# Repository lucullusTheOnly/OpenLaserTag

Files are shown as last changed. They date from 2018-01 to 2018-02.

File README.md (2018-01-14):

# OpenLaserTag
OperLaserTag is a DIY system for the popular game lasertag. I have designed it for high flexibility for game modes. With this article series and a little knowledge about electronics with microcontrollers like the Arduino you should be able to build your own lasertag system.
The work on this project isn't finished jet and I would be glad to receive some honest hints about what the system should be able to do and how this can be accomplished.

The System consists of the Arduino-based tagger, which is connected to a smartphone via bluetooth. The tagger uses an infrared LED and a lens to send a beam of modulated IR-light in the direction the tagger is pointed to. This works similar to normal IR-remotes, for example for your TV. The tagger is connected to a number of receiver modules, which are located on a vest, so that you can be hit by other players with their tagger. The Arduino informs the smartphone whenever something happens via a bluetooth-serial module and the smartphone does all the management of the game.

At the current state the tagger systems of different players don't have any contact. I designed the system, so that the game follows rules written in a XML-file and will end in a given time limit. This gives great flexibility, because you don't have to set up a communication system over the whole game field (which may be quite big). But this feature (over a limited range) could be added using 433MHz transmission modules.

For more information please visit the Wiki.

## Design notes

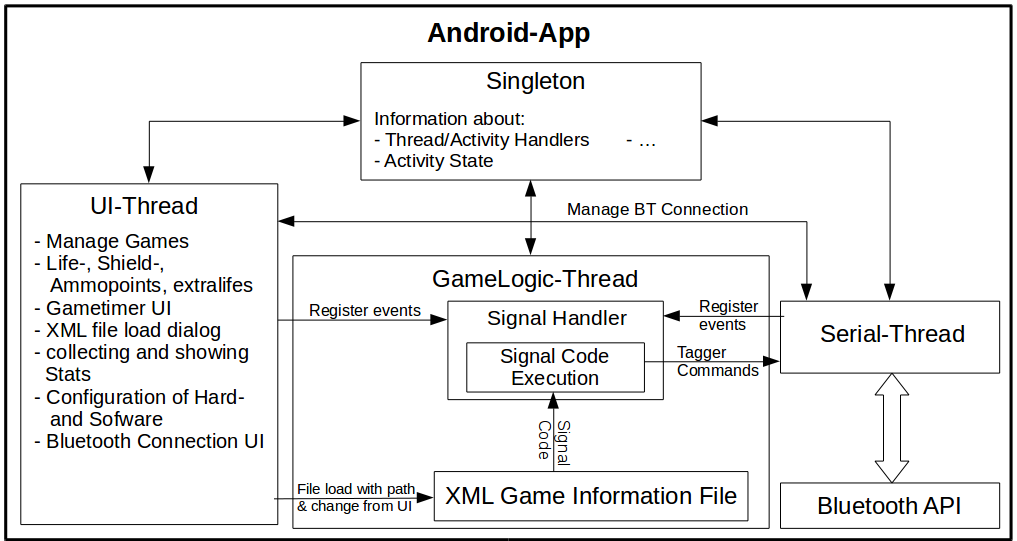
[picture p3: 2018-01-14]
Wiki/LaserTag_schematic_app.png

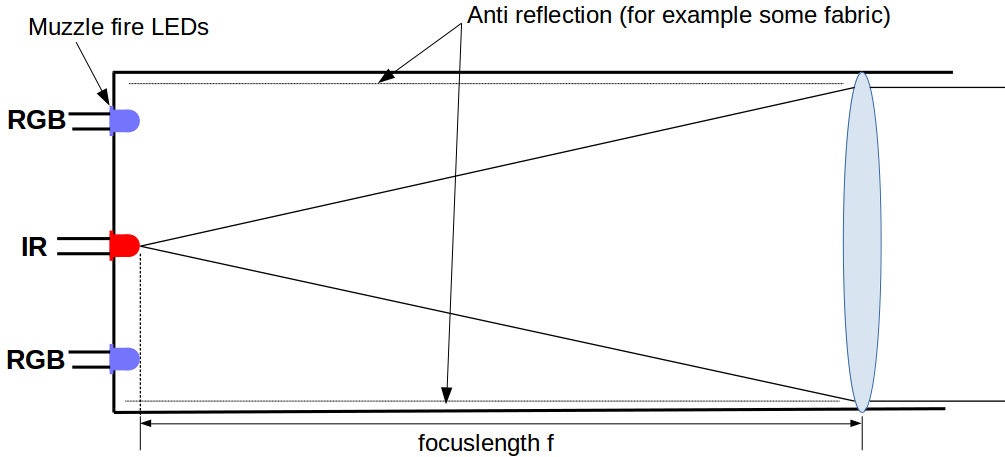
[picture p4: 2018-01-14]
Wiki/LaserTag_schematic_fire_tube.png

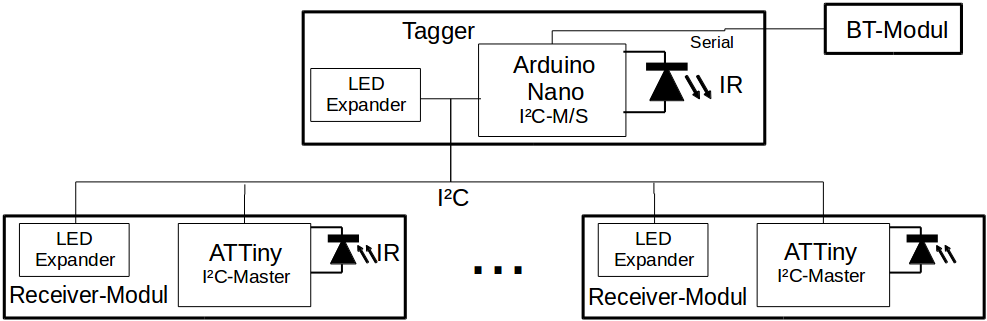
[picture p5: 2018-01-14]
Wiki/LaserTag_schematic_tagger.png

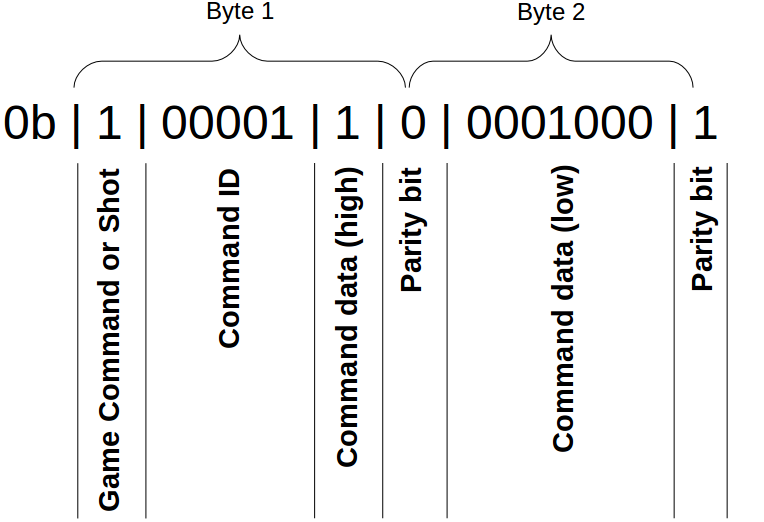
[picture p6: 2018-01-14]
Wiki/LaserTag_IR_protocol_game_commands.png

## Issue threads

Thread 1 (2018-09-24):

What license?

gldhnchn, 2018-09-24:
Under which license is this Repository?

Is it allowed to fork, modify and build an own laser tag system from this one?

lucullusTheOnly, 2020-01-31:
I haven't thought of a license, also because I currently have frozen this project ( I got into a dead end with my receiver system). But it is free to use and modify for everyone. Do as you like with the code

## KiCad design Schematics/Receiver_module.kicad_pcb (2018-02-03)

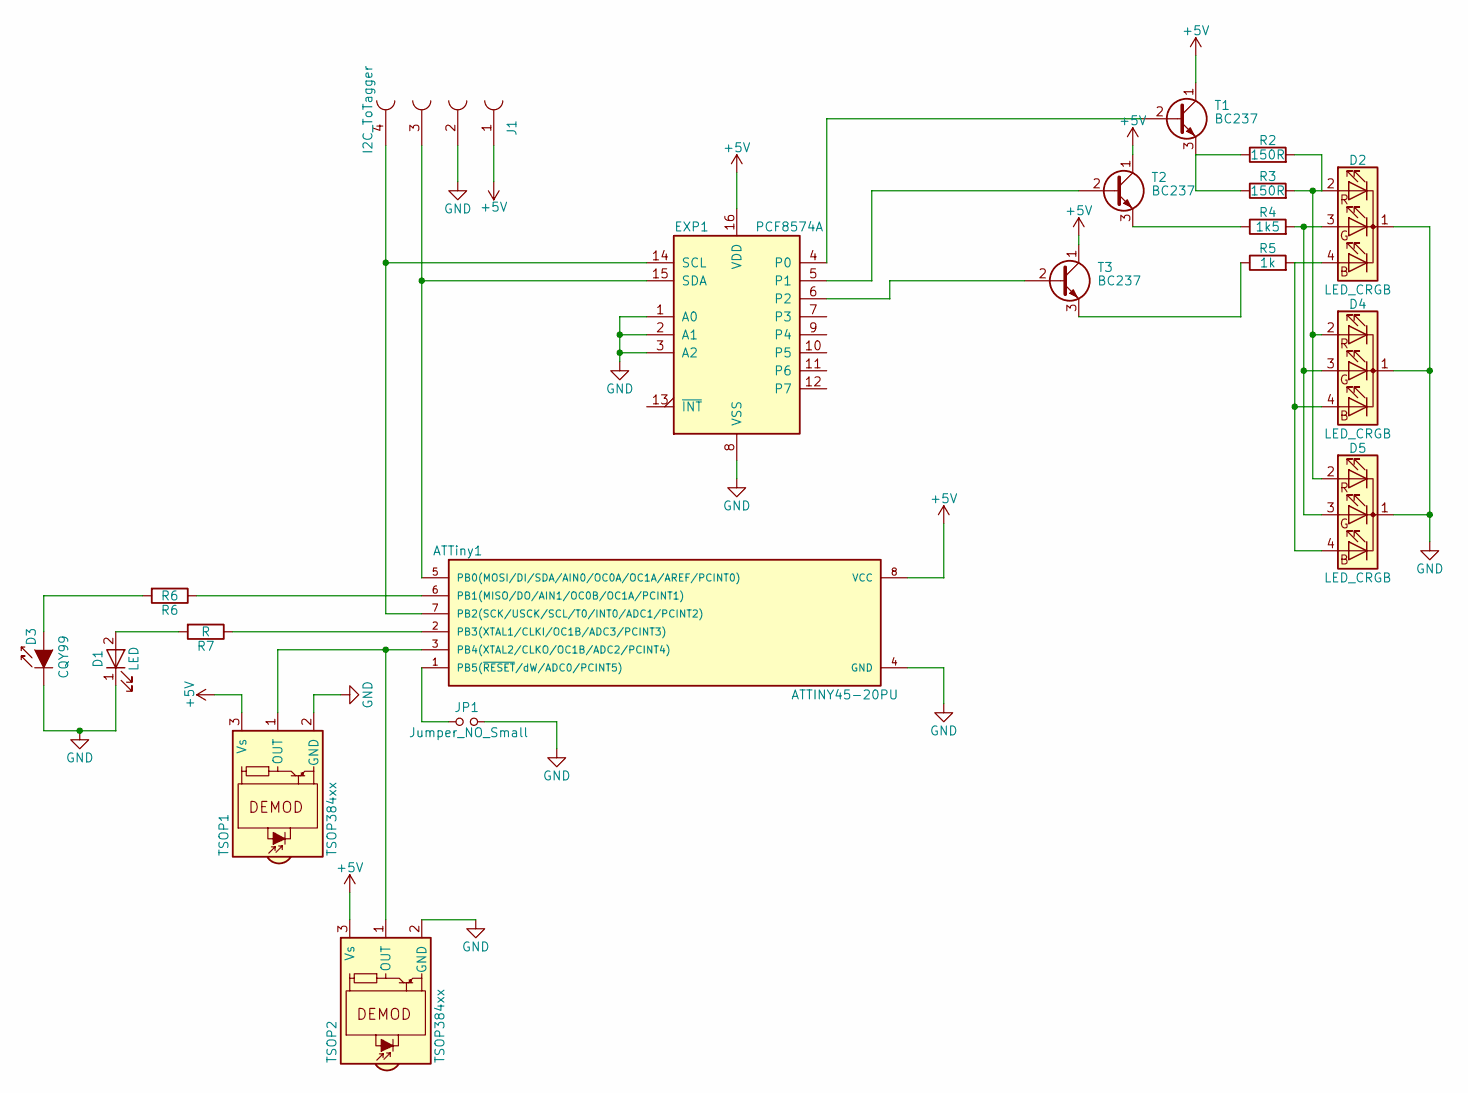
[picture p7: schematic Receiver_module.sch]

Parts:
ATTiny1: ATTINY45-20PU; DIP-8_W7.62mm
D1: LED; LED_D5.0mm_FlatTop
D2, D4, D5: LED_CRGB; LED_D5.0mm-4
D3: CQY99; LED_D5.0mm_FlatTop
EXP1: PCF8574A; DIP-16_W7.62mm_Socket
J1: I2C_ToTagger; SDL-104-X-XX_2x02
JP1: Jumper_NO_Small; Pin_Header_Straight_1x02_Pitch2.54mm
R2, R3: 150R; R_Axial_DIN0204_L3.6mm_D1.6mm_P2.54mm_Vertical
R4: 1k5; R_Axial_DIN0204_L3.6mm_D1.6mm_P2.54mm_Vertical
R5: 1k; R_Axial_DIN0204_L3.6mm_D1.6mm_P2.54mm_Vertical
R6: R6; R_Axial_DIN0204_L3.6mm_D1.6mm_P2.54mm_Vertical
R7: R; R_Axial_DIN0204_L3.6mm_D1.6mm_P2.54mm_Vertical
T1, T2, T3: BC237; TO-92_Inline_Narrow_Oval
TSOP1, TSOP2: TSOP384xx; IRReceiver_Vishay_MINICAST-3pin

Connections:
+5V: ATTiny1.8 (VCC), EXP1.16 (VDD), J1.1, T1.1 (C), T2.1 (C), T3.1 (C), TSOP1.3 (Vs), TSOP2.3 (Vs)
GND: ATTiny1.4 (GND), D1.1 (K), D2.1 (K), D3.1 (K), D4.1 (K), D5.1 (K), EXP1.1 (A0), EXP1.2 (A1), EXP1.3 (A2), EXP1.8 (VSS), J1.2, JP1.2, TSOP1.2 (GND), TSOP2.2 (GND)
unnamed: ATTiny1.1 (PB5(~RESET~/dW/ADC0/PCINT5)), JP1.1
unnamed: ATTiny1.2 (PB3(XTAL1/CLKI/OC1B/ADC3/PCINT3)), R7.1
unnamed: ATTiny1.3 (PB4(XTAL2/CLKO/OC1B/ADC2/PCINT4)), TSOP1.1 (OUT), TSOP2.1 (OUT)
unnamed: ATTiny1.5 (PB0(MOSI/DI/SDA/AIN0/OC0A/OC1A/AREF/PCI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), EXP1.15 (SDA), J1.3
unnamed: ATTiny1.6 (PB1(MISO/DO/AIN1/OC0B/OC1A/PCINT1)), R6.1
unnamed: ATTiny1.7 (PB2(SCK/USCK/SCL/T0/INT0/ADC1/PCINT2)), EXP1.14 (SCL), J1.4
unnamed: D1.2 (A), R7.2
unnamed: D2.2 (RA), D4.2 (RA), D5.2 (RA), R2.2, R3.2
unnamed: D2.3 (GA), D4.3 (GA), D5.3 (GA), R4.2
unnamed: D2.4 (BA), D4.4 (BA), D5.4 (BA), R5.2
unnamed: D3.2 (A), R6.2
unnamed: EXP1.4 (P0), T1.2 (B)
unnamed: EXP1.5 (P1), T2.2 (B)
unnamed: EXP1.6 (P2), T3.2 (B)
unnamed: R2.1, R3.1, T1.3 (E)
unnamed: R4.1, T2.3 (E)
unnamed: R5.1, T3.3 (E)

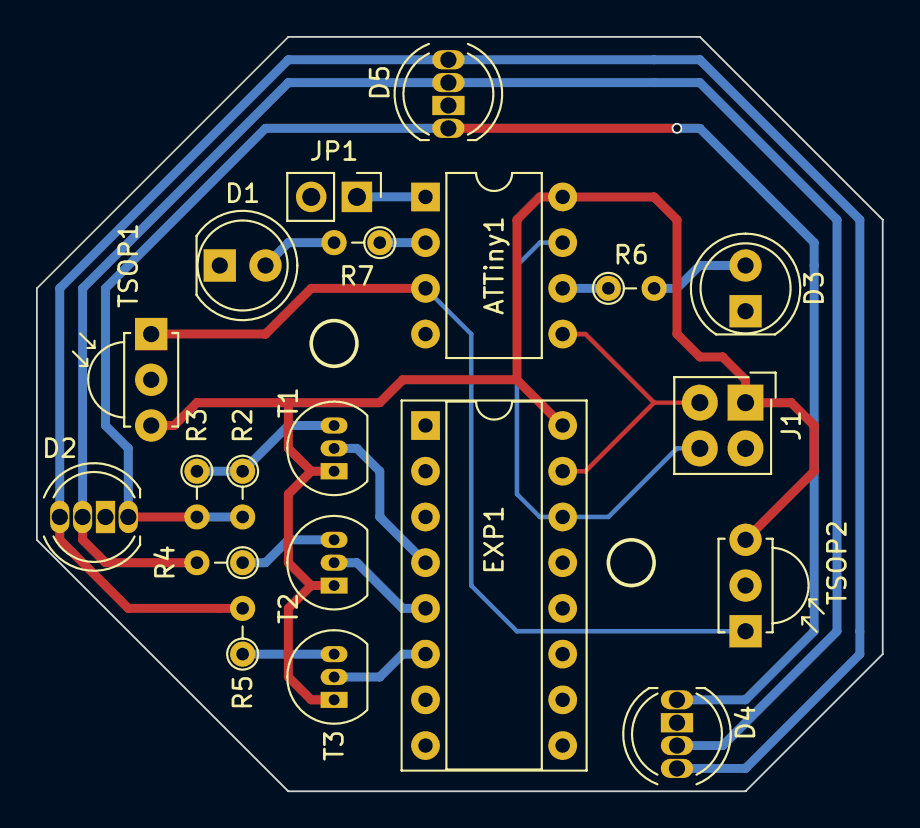
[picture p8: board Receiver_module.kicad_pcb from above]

Board: 2 copper layers, 47.0 x 41.9 mm, 20 parts (0 on the bottom side), 19 nets.

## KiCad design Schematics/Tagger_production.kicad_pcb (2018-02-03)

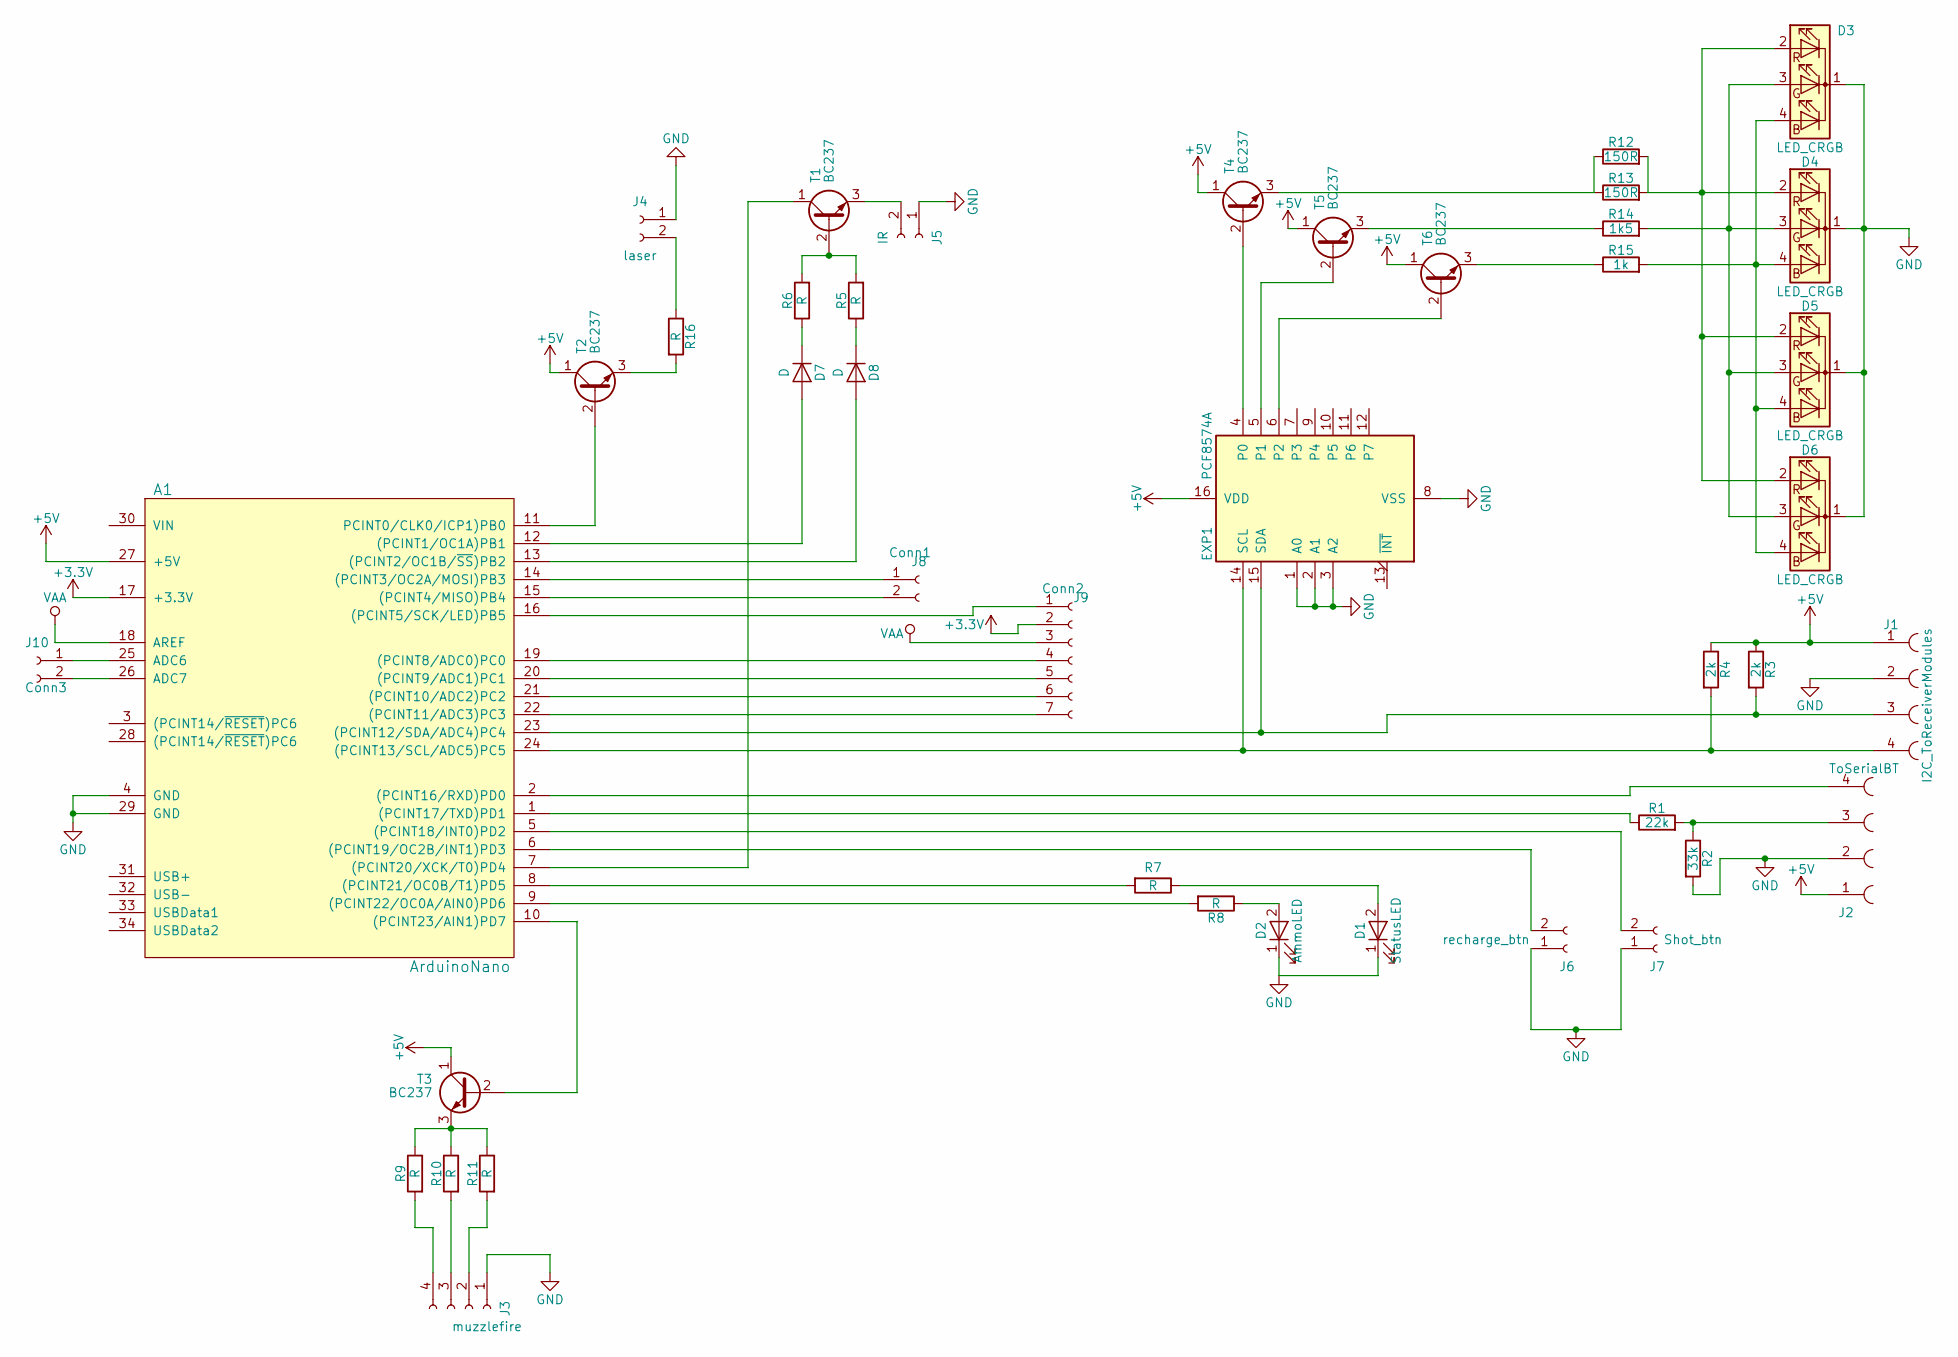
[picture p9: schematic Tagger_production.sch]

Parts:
A1: ArduinoNano
D1: StatusLED; LED_D5.0mm_FlatTop
D2: AmmoLED; LED_D5.0mm_FlatTop
D3, D4, D5, D6: LED_CRGB; LED_D5.0mm-4
D7, D8: D; D_A-405_P2.54mm_Vertical_KathodeUp
EXP1: PCF8574A; DIP-16_W7.62mm
J1: I2C_ToReceiverModules; SDL-104-X-XX_2x02
J2: ToSerialBT; Socket_Strip_Angled_1x04_Pitch2.54mm
J3: muzzlefire; Socket_Strip_Straight_1x04_Pitch2.54mm
J4: laser; Socket_Strip_Straight_1x02_Pitch2.54mm
J5: IR; Socket_Strip_Straight_1x02_Pitch2.54mm
J6: recharge_btn; Socket_Strip_Straight_1x02_Pitch2.54mm
J7: Shot_btn; Socket_Strip_Straight_1x02_Pitch2.54mm
J8: Conn1; Socket_Strip_Straight_1x02_Pitch2.54mm
J9: Conn2; Socket_Strip_Straight_1x07_Pitch2.54mm
J10: Conn3; Socket_Strip_Straight_1x02_Pitch2.54mm
R1: 22k; R_Axial_DIN0207_L6.3mm_D2.5mm_P2.54mm_Vertical
R2: 33k; R_Axial_DIN0207_L6.3mm_D2.5mm_P2.54mm_Vertical
R3, R4: 2k; R_Axial_DIN0207_L6.3mm_D2.5mm_P2.54mm_Vertical
R5, R6, R7, R8, R9, R10, R11, R16: R; R_Axial_DIN0207_L6.3mm_D2.5mm_P2.54mm_Vertical
R12, R13: 150R; R_Axial_DIN0207_L6.3mm_D2.5mm_P2.54mm_Vertical
R14: 1k5; R_Axial_DIN0207_L6.3mm_D2.5mm_P2.54mm_Vertical
R15: 1k; R_Axial_DIN0207_L6.3mm_D2.5mm_P2.54mm_Vertical
T1, T2, T3, T4, T5, T6: BC237; TO-92_Inline_Narrow_Oval

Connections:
+3V3: A1.17 (+3.3V), J9.2
+5V: A1.27 (+5V), EXP1.16 (VDD), J1.1, J2.1, R3.1, R4.1, T2.1 (C), T3.1 (C), T4.1 (C), T5.1 (C), T6.1 (C)
GND: A1.4 (GND), A1.29 (GND), D1.1 (K), D2.1 (K), D3.1 (K), D4.1 (K), D5.1 (K), D6.1 (K), EXP1.1 (A0), EXP1.2 (A1), EXP1.3 (A2), EXP1.8 (VSS), J1.2, J2.2, J3.1, J4.1, J5.1, J6.1, J7.1, R2.2
unnamed: A1.1 ((PCINT17/TXD)PD1), R1.1
unnamed: A1.2 ((PCINT16/RXD)PD0), J2.4
unnamed: A1.5 ((PCINT18/INT0)PD2), J7.2
unnamed: A1.6 ((PCINT19/OC2B/INT1)PD3), J6.2
unnamed: A1.7 ((PCINT20/XCK/T0)PD4), T1.1 (C)
unnamed: A1.8 ((PCINT21/OC0B/T1)PD5), R7.2
unnamed: A1.9 ((PCINT22/OC0A/AIN0)PD6), R8.2
unnamed: A1.10 ((PCINT23/AIN1)PD7), T3.2 (B)
unnamed: A1.11 (PCINT0/CLK0/ICP1)PB0), T2.2 (B)
unnamed: A1.12 ((PCINT1/OC1A)PB1), D7.2 (A)
unnamed: A1.13 ((PCINT2/OC1B/~SS~)PB2), D8.2 (A)
unnamed: A1.14 ((PCINT3/OC2A/MOSI)PB3), J8.1
unnamed: A1.15 ((PCINT4/MISO)PB4), J8.2
unnamed: A1.16 ((PCINT5/SCK/LED)PB5), J9.1
unnamed: A1.19 ((PCINT8/ADC0)PC0), J9.4
unnamed: A1.20 ((PCINT9/ADC1)PC1), J9.5
unnamed: A1.21 ((PCINT10/ADC2)PC2), J9.6
unnamed: A1.22 ((PCINT11/ADC3)PC3), J9.7
unnamed: A1.23 ((PCINT12/SDA/ADC4)PC4), EXP1.15 (SDA), J1.3, R3.2
unnamed: A1.24 ((PCINT13/SCL/ADC5)PC5), EXP1.14 (SCL), J1.4, R4.2
unnamed: A1.25 (ADC6), J10.1
unnamed: A1.26 (ADC7), J10.2
unnamed: D1.2 (A), R7.1
unnamed: D2.2 (A), R8.1
unnamed: D3.2 (RA), D4.2 (RA), D5.2 (RA), D6.2 (RA), R12.2, R13.2
unnamed: D3.3 (GA), D4.3 (GA), D5.3 (GA), D6.3 (GA), R14.2
unnamed: D3.4 (BA), D4.4 (BA), D5.4 (BA), D6.4 (BA), R15.2
unnamed: D7.1 (K), R6.1
unnamed: D8.1 (K), R5.1
unnamed: EXP1.4 (P0), T4.2 (B)
unnamed: EXP1.5 (P1), T5.2 (B)
unnamed: EXP1.6 (P2), T6.2 (B)
unnamed: J2.3, R1.2, R2.1
unnamed: J3.2, R11.2
unnamed: J3.3, R10.2
unnamed: J3.4, R9.2
unnamed: J4.2, R16.1
unnamed: J5.2, T1.3 (E)
unnamed: R5.2, R6.2, T1.2 (B)
unnamed: R9.1, R10.1, R11.1, T3.3 (E)
unnamed: R12.1, R13.1, T4.3 (E)
unnamed: R14.1, T5.3 (E)
unnamed: R15.1, T6.3 (E)
unnamed: R16.2, T2.3 (E)
VAA: A1.18 (AREF), J9.3

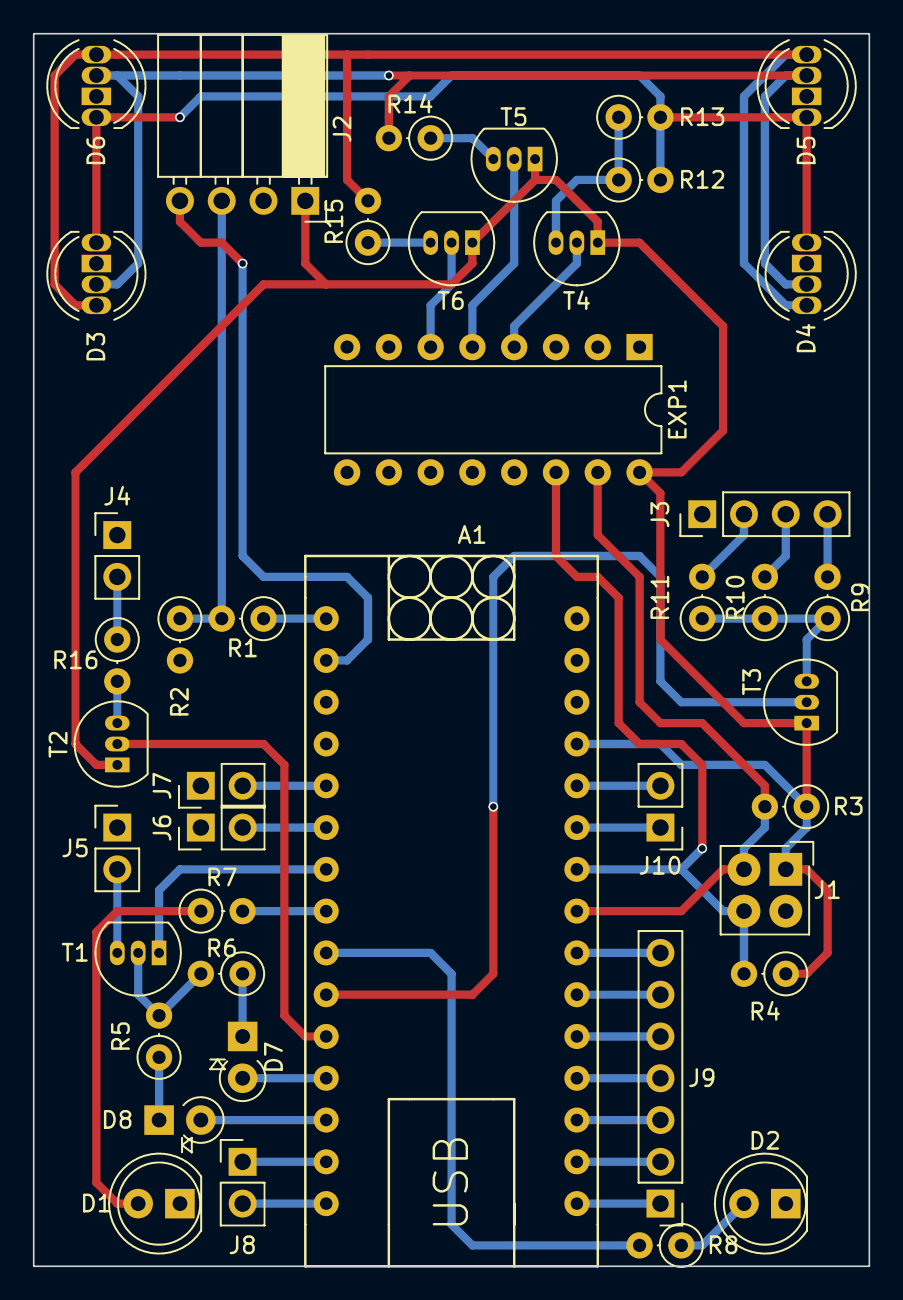
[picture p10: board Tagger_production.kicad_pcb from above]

Board: 2 copper layers, 50.8 x 74.9 mm, 42 parts (0 on the bottom side), 48 nets.

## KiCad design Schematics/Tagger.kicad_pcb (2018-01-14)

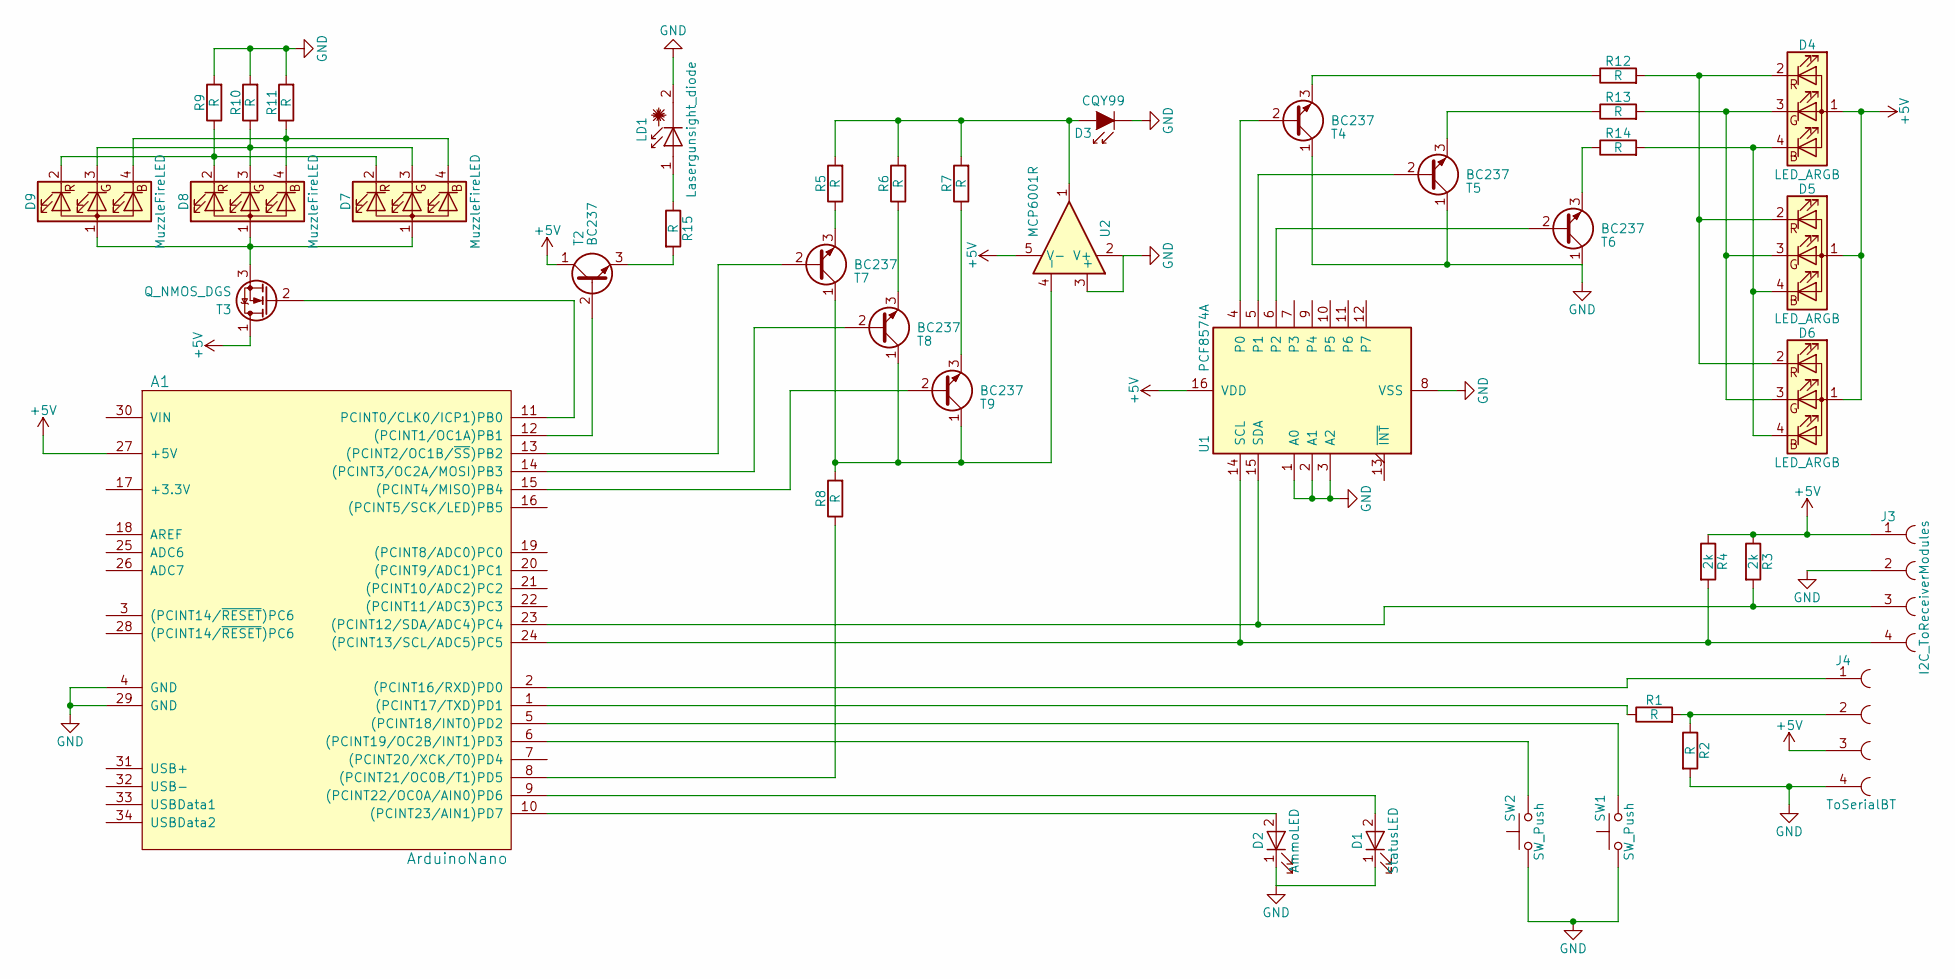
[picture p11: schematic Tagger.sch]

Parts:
A1: ArduinoNano
D1: StatusLED; LED_D5.0mm_FlatTop
D2: AmmoLED; LED_D5.0mm_FlatTop
D3: CQY99; LED_D5.0mm_FlatTop
D4, D5, D6: LED_ARGB; LED_D5.0mm-4
D7, D8, D9: MuzzleFireLED; LED_D5.0mm-4
J3: I2C_ToReceiverModules; SDL-104-X-XX_2x02
J4: ToSerialBT; Pin_Header_Angled_1x04_Pitch2.54mm
LD1: Lasergunsight_diode; Pin_Header_Straight_1x02_Pitch2.54mm
R1, R2, R5, R6, R7, R8, R9, R10, R11, R12, R13, R14, R15: R; R_Axial_DIN0207_L6.3mm_D2.5mm_P2.54mm_Vertical
R3, R4: 2k; R_Axial_DIN0207_L6.3mm_D2.5mm_P2.54mm_Vertical
SW1, SW2: SW_Push; Pin_Header_Straight_1x02_Pitch2.54mm
T2, T4, T5, T6, T7, T8, T9: BC237; TO-92_Molded_Narrow
T3: Q_NMOS_DGS; TO-126_Vertical
U1: PCF8574A; DIP-16_W7.62mm
U2: MCP6001R; DIP-8_W7.62mm

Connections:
+5V: A1.27 (+5V), D4.1 (A), D5.1 (A), D6.1 (A), J3.1, J4.3, R3.1, R4.1, T2.1 (C), T3.1 (D), U1.16 (VDD), U2.5 (V-)
GND: A1.4 (GND), A1.29 (GND), D1.1 (K), D2.1 (K), D3.1 (K), J3.2, J4.4, LD1.2 (K), R2.2, R9.2, R10.2, R11.2, SW1.1, SW2.1, T4.1 (C), T5.1 (C), T6.1 (C), U1.1 (A0), U1.2 (A1), U1.3 (A2), U1.8 (VSS), U2.2 (V+), U2.3 (+)
unnamed: A1.1 ((PCINT17/TXD)PD1), R1.1
unnamed: A1.2 ((PCINT16/RXD)PD0), J4.1
unnamed: A1.5 ((PCINT18/INT0)PD2), SW1.2
unnamed: A1.6 ((PCINT19/OC2B/INT1)PD3), SW2.2
unnamed: A1.8 ((PCINT21/OC0B/T1)PD5), R8.1
unnamed: A1.9 ((PCINT22/OC0A/AIN0)PD6), D1.2 (A)
unnamed: A1.10 ((PCINT23/AIN1)PD7), D2.2 (A)
unnamed: A1.11 (PCINT0/CLK0/ICP1)PB0), T3.2 (G)
unnamed: A1.12 ((PCINT1/OC1A)PB1), T2.2 (B)
unnamed: A1.13 ((PCINT2/OC1B/~SS~)PB2), T7.2 (B)
unnamed: A1.14 ((PCINT3/OC2A/MOSI)PB3), T8.2 (B)
unnamed: A1.15 ((PCINT4/MISO)PB4), T9.2 (B)
unnamed: A1.23 ((PCINT12/SDA/ADC4)PC4), J3.3, R3.2, U1.15 (SDA)
unnamed: A1.24 ((PCINT13/SCL/ADC5)PC5), J3.4, R4.2, U1.14 (SCL)
unnamed: D3.2 (A), R5.2, R6.2, R7.2, U2.1
unnamed: D4.2 (RK), D5.2 (RK), D6.2 (RK), R12.2
unnamed: D4.3 (GK), D5.3 (GK), D6.3 (GK), R13.2
unnamed: D4.4 (BK), D5.4 (BK), D6.4 (BK), R14.2
unnamed: D7.1 (A), D8.1 (A), D9.1 (A), T3.3 (S)
unnamed: D7.2 (RK), D8.2 (RK), D9.2 (RK), R9.1
unnamed: D7.3 (GK), D8.3 (GK), D9.3 (GK), R10.1
unnamed: D7.4 (BK), D8.4 (BK), D9.4 (BK), R11.1
unnamed: J4.2, R1.2, R2.1
unnamed: LD1.1 (A), R15.1
unnamed: R5.1, T7.3 (E)
unnamed: R6.1, T8.3 (E)
unnamed: R7.1, T9.3 (E)
unnamed: R8.2, T7.1 (C), T8.1 (C), T9.1 (C), U2.4 (-)
unnamed: R12.1, T4.3 (E)
unnamed: R13.1, T5.3 (E)
unnamed: R14.1, T6.3 (E)
unnamed: R15.2, T2.3 (E)
unnamed: T4.2 (B), U1.4 (P0)
unnamed: T5.2 (B), U1.5 (P1)
unnamed: T6.2 (B), U1.6 (P2)

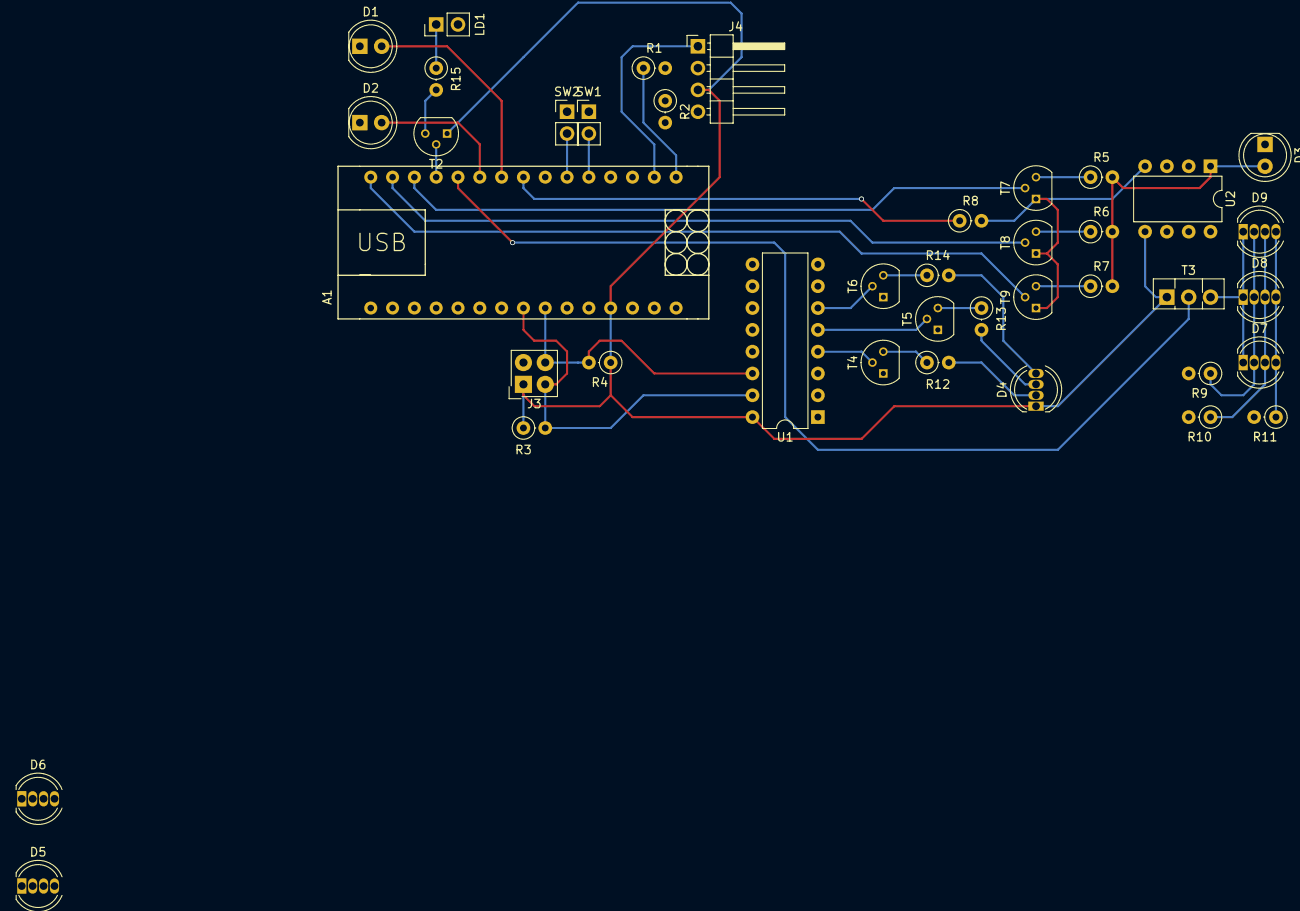
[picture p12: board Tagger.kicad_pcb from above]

Board: 2 copper layers, 40 parts (0 on the bottom side), 37 nets.

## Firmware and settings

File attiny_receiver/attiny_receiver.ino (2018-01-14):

#include <TinyWire.h>
#include <EEPROM.h>

// definitions of pins
#define IR_pin 4
#define led_pin 1
#define ir_led 3

// generic definies
#define address_ID_offset 11 // receiver addresses start at 11
#define timeout 20000 // detection timeout for IR code
#define I2Ctransmission_retries 3

// definition of IR default values
#define DEFAULT_DURATION_START 800
#define DEFAULT_DURATION_ONE   200
#define DEFAULT_DURATION_ZERO  500
#define DEFAULT_PULSE_DELAY    500

byte ID = 0; // ID of this receiver. Has to be set different for every used receiver in one system
byte nano_address = 10;

byte I2C_buffer[6]={0,0,0,0,0,0};
byte I2C_pos=0;

unsigned int pulse_length[16];
unsigned int bitvalues16[16] = {32768, 16384, 8192, 4096, 2048, 1024, 512, 256, 128, 64, 32, 16, 8, 4, 2, 1};
unsigned int bit_num=0;
boolean start_detected = false;
boolean send_please=false;
unsigned int value=0;

unsigned int I2Canswer=0;

byte blink_state=0;
unsigned long blink_timestamp=0;

// IR pulse lengths
#define delayus             6  // pulse length for IR modulation. value of 6 for use with tsop4838 IR Receiver chip
unsigned long duration_zero=500;
unsigned long duration_one=200;
unsigned long duration_start=800;
unsigned long pulse_delay=500;
unsigned long bytes_delay=2000;
unsigned long start_lower=750;
unsigned long start_upper=1000;
unsigned long one_lower=150;
unsigned long one_upper=400;
unsigned long zero_lower=400;
unsigned long zero_upper=750;

// variable, that holds the IR-Code, that should be send
unsigned int shot=0;


// functions for detecting the correspondig IR pulse lengths
boolean is_one(unsigned long l){
  if(l>one_lower && l<=one_upper) return true;
  return false;
}

boolean is_zero(unsigned long l){
  if(l>zero_lower && l<=zero_upper) return true;
  return false;
}

boolean is_start(unsigned long l){
  if(l>start_lower && l<=start_upper) return true;
  return false;
}

// Parity Check function
// Returns 1 (ODD) or 0 (EVEN) parity
int parity (unsigned char x)
{
    x = x ^ x >> 4;
    x = x ^ x >> 2;
    x = x ^ x >> 1;
    return x & 1;
}

// displays I2C errors as LED blinking for debug purposes
void show_error(byte error){
  for(int i=0;i<error;i++){
    digitalWrite(led_pin,HIGH);
    delay(400);
    digitalWrite(led_pin,LOW);
    delay(400);
  }
}

void setup() {
  // set pinmodes
  pinMode(IR_pin, INPUT);
  pinMode(led_pin, OUTPUT);
  digitalWrite(led_pin,HIGH);
  pinMode(ir_led, OUTPUT);

  // load ir config constants from EEPROM
  // duration start
  if(EEPROM.read(0)!= 255 || EEPROM.read(1)!= 255){
    duration_start = (EEPROM.read(0)<<8) | EEPROM.read(1);
  } else {
    duration_start = DEFAULT_DURATION_START;
    EEPROM.update(0, (duration_start&0xFF00)>>8);
    EEPROM.update(1, duration_start&0xFF);
  }
  // duration one
  if(EEPROM.read(2)!= 255 || EEPROM.read(3)!= 255){
    duration_one = (EEPROM.read(2)<<8) | EEPROM.read(3);
  } else {
    duration_one = DEFAULT_DURATION_ONE;
    EEPROM.update(2, (duration_one&0xFF00)>>8);
    EEPROM.update(3, duration_one&0xFF);
  }
  // duration zero
  if(EEPROM.read(4)!= 255 || EEPROM.read(5)!= 255){
    duration_zero = (EEPROM.read(4)<<8) | EEPROM.read(5);
  } else {
    duration_zero = DEFAULT_DURATION_ZERO;
    EEPROM.update(4, (duration_zero&0xFF00)>>8);
    EEPROM.update(5, duration_zero&0xFF);
  }
  // pulse delay
  if(EEPROM.read(6)!= 255 || EEPROM.read(7)!= 255){
    pulse_delay = (EEPROM.read(6)<<8) | EEPROM.read(7);
  } else {
    pulse_delay = DEFAULT_PULSE_DELAY;
    EEPROM.update(6, (pulse_delay&0xFF00)>>8);
    EEPROM.update(7, pulse_delay&0xFF);
  }
  update_pulse_limits();

  // Initiate the TinyWire library (for I2C communication) as slave
  TinyWire.begin(ID+address_ID_offset);

  // clear pulse length array
  for(int i=0;i<16;i++) pulse_length[i]=0;
}

void loop() {
  // I2C Code
  if(TinyWire.available()>0){
    switch(TinyWire.read()){
      case 'I': // ID was requested
        TinyWire.beginTransmission(nano_address);
        TinyWire.send('I');
        TinyWire.send(ID);
        I2Canswer = TinyWire.endTransmission();
        break;
      case 'i': // new IR pulse config was transmitted
        byte i2cbuffer[8];
        for(int i=0;i<8;i++){
          if(TinyWire.available()==0) return;
          i2cbuffer[i]=TinyWire.read();
        }
        duration_start = i2cbuffer[0]<<8;
        duration_start |= i2cbuffer[1];
        EEPROM.update(0, (duration_start&0xFF00)>>8);
        EEPROM.update(1, duration_start&0xFF);
        duration_one = i2cbuffer[2]<<8;
        duration_one |= i2cbuffer[3];
        EEPROM.update(2, (duration_one&0xFF00)>>8);
        EEPROM.update(3, duration_one&0xFF);
        duration_zero = i2cbuffer[4]<<8;
        duration_zero |= i2cbuffer[5];
        EEPROM.update(4, (duration_zero&0xFF00)>>8);
        EEPROM.update(5, duration_zero&0xFF);
        pulse_delay = i2cbuffer[6]<<8;
        pulse_delay |= i2cbuffer[7];
        EEPROM.update(6, (pulse_delay&0xFF00)>>8);
        EEPROM.update(7, pulse_delay&0xFF);
        update_pulse_limits();
        break ;
      case 'c': // send IR command through receiver IR LED
        if(TinyWire.available()==0) break;
        shot = TinyWire.read() << 8;
        if(TinyWire.available()==0) break;
        shot |= TinyWire.read();
        morse_word(shot);
        break;
      case 'b': // blink for identifying the receiver
        blink_state=1;
        break;
      case 'p': // send receiver ping to nano (for time measurement)
        TinyWire.beginTransmission(nano_address);
        TinyWire.send('p');
        I2Canswer = TinyWire.endTransmission();
        break;
    }
  }

  // Received shot I2C code (sending shot bytes to nano)
  if(send_please) {
    value=0;
    // check pulse lengths for adding up the whole transmitted value
    for(int i=0;i<16;i++){
      if(is_one(pulse_length[i])){
        value+=bitvalues16[i];
      } else if(!is_zero(pulse_length[i])){ // pulse was invalid
        send_please = false;
        for(int i=0;i<16;i++) pulse_length[i]=0;
        return;
      }
      pulse_length[i]=0;
    }

    // divide in bytes, check parity and transmit bytes to nano
    byte high_value = (value & 0xFF00) >> 8;
    byte low_value = value & 0xFF;
    if(parity(high_value)==0 || parity(low_value)==0){ // parity check was ok
      TinyWire.beginTransmission(nano_address);
      TinyWire.send('s');
      TinyWire.send(ID); // send ID for checking, where player was hit
      TinyWire.send(high_value);
      TinyWire.send(low_value);
      I2Canswer = TinyWire.endTransmission();
      if(I2Canswer!=0){
        byte i=0;
        do{
          if(i==I2Ctransmission_retries) {
            show_error(I2Canswer); // on I2C error, show through blinking for debug purposes
            return;
          }
          delay(4);
          TinyWire.beginTransmission(nano_address);
          TinyWire.send('s');
          TinyWire.send(ID); // send ID for checking, where player was hit
          TinyWire.send(high_value);
          TinyWire.send(low_value);
          I2Canswer = TinyWire.endTransmission();
          i++;
        } while(I2Canswer!=0); // retry was successfull
      }
      blink_state = 1;// activate blink code
    }

    // reset for next pulse
    for(int i=0;i<16;i++) pulse_length[i]=0;
    send_please=false;
  }

  // Blink code (non-blocking)
  if(blink_state > 0 && millis()-blink_timestamp > 50){
    blink_timestamp = millis();
    PORTB ^= 1 << led_pin;
    blink_state++;
    if(blink_state > 14) {blink_state=0;PORTB |= 1 << led_pin;}
  }

  // IR Code
  unsigned long timestamp = micros();
  while(PINB & 0b10000) { //wait for ir pin to go low
    if(micros()-timestamp > timeout){
      return;
    }
  }
  timestamp = micros();
  while(!(PINB & 0b10000)) { // wait for ir pin to go high again
    if(micros()-timestamp > timeout) {
      delay(1);
      return;
    }
  }
  unsigned long temp_length = micros() - timestamp;
  // put measured pulse lengths in array corresponding to detected start puls
  if(is_start(temp_length)) {
    bit_num = 0;
    start_detected = true;
  } else {
    pulse_length[bit_num] = temp_length;
    bit_num++;
    if(bit_num>15 && start_detected) {
      bit_num = 0;
      send_please=true;
      start_detected = false;
    }
  }

  // Reset I2C Software to prevet block of library (hotfix, quick and dirty)
  if(millis()-TinyWire.LastActiveTimestamp()>1000){
    TinyWire.begin(ID+address_ID_offset);
  }
}


// update limits for pulse detection
//    50 is added to the duration due to effects of the receiver IC
void update_pulse_limits(){
  unsigned long one_epsilon=(duration_zero-duration_one)/2;
  one_upper = duration_one + 50 + one_epsilon;
  one_lower = duration_one + 50 - one_epsilon;
  if(one_lower > 40000) one_lower = 1;
  unsigned long start_epsilon=(duration_start-duration_zero)/2;
  start_upper = duration_start + 50 + start_epsilon;
  start_lower = duration_start + 50 - start_epsilon;
  zero_upper = start_lower;
  zero_lower = one_upper;
}

// Pulses the IR LED for the specified duration, so that the receiver
//    IC detects it
void pulse(unsigned long duration)// duration in microseconds
{
  unsigned long start_time=micros();
  while(micros()-start_time<duration) 
  //for(unsigned int i=0;i<times;i++)
  {
    digitalWrite(ir_led, HIGH);
    delayMicroseconds(delayus);
    digitalWrite(ir_led, LOW);
    delayMicroseconds(delayus);
  }
  delayMicroseconds(pulse_delay);
}

// Send one byte over IR
void morse_byte(unsigned char c)
{
  pulse(duration_start);//startpulse
  if((c&0b10000000)!=0) pulse(duration_one);
  else      pulse(duration_zero);
  if((c&0b01000000)!=0) pulse(duration_one);
  else      pulse(duration_zero);
  if((c&0b00100000)!=0) pulse(duration_one);
  else      pulse(duration_zero);
  if((c&0b00010000)!=0) pulse(duration_one);
  else      pulse(duration_zero);
  if((c&0b00001000)!=0) pulse(duration_one);
  else      pulse(duration_zero);
  if((c&0b00000100)!=0) pulse(duration_one);
  else      pulse(duration_zero);
  if((c&0b00000010)!=0) pulse(duration_one);
  else      pulse(duration_zero);
  if((c&0b00000001)!=0) pulse(duration_one);
  else      pulse(duration_zero);
  delayMicroseconds(bytes_delay);
}

// Send two bytes (one word) over IR
void morse_word(unsigned int c)
{
  pulse(duration_start);//startpulse
  if((c&0b1000000000000000)!=0) pulse(duration_one);
  else      pulse(duration_zero);
  if((c&0b0100000000000000)!=0) pulse(duration_one);
  else      pulse(duration_zero);
  if((c&0b0010000000000000)!=0) pulse(duration_one);
  else      pulse(duration_zero);
  if((c&0b0001000000000000)!=0) pulse(duration_one);
  else      pulse(duration_zero);
  if((c&0b0000100000000000)!=0) pulse(duration_one);
  else      pulse(duration_zero);
  if((c&0b0000010000000000)!=0) pulse(duration_one);
  else      pulse(duration_zero);
  if((c&0b0000001000000000)!=0) pulse(duration_one);
  else      pulse(duration_zero);
  if((c&0b0000000100000000)!=0) pulse(duration_one);
  else      pulse(duration_zero);
  if((c&0b0000000010000000)!=0) pulse(duration_one);
  else      pulse(duration_zero);
  if((c&0b0000000001000000)!=0) pulse(duration_one);
  else      pulse(duration_zero);
  if((c&0b0000000000100000)!=0) pulse(duration_one);
  else      pulse(duration_zero);
  if((c&0b0000000000010000)!=0) pulse(duration_one);
  else      pulse(duration_zero);
  if((c&0b0000000000001000)!=0) pulse(duration_one);
  else      pulse(duration_zero);
  if((c&0b0000000000000100)!=0) pulse(duration_one);
  else      pulse(duration_zero);
  if((c&0b0000000000000010)!=0) pulse(duration_one);
  else      pulse(duration_zero);
  if((c&0b0000000000000001)!=0) pulse(duration_one);
  else      pulse(duration_zero);
  delayMicroseconds(bytes_delay);
}

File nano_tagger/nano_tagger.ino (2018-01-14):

#include <Wire.h>
#include <TimerOne.h>
#include <EEPROM.h>

// Pin definitions
#define ir_led              5
#define rled                6
#define trigger_pin         2
#define recharge_pin        3
#define ammo_indicator_pin  7
#define muzzlefire_pin      8
#define laser_gunsight_pin  9

#define minReceiverID       11
#define maxReceiverID       30

#define expander_address    0b0111000  // address of all expander chips for driving the RGB LEDs

#define button_delay        3 // debounce time for button presses in units of 20ms

#define MUZZLEFIRE_DURATION 18      // Muzzlefire duration in units of 20ms
#define MUZZLEFIRE_BLINK_DURATION 2 // half period of muzzlefire in units of 20ms

// definition of IR default values
#define DEFAULT_DURATION_START 800
#define DEFAULT_DURATION_ONE   200
#define DEFAULT_DURATION_ZERO  500
#define DEFAULT_PULSE_DELAY    500

// IR pulse lengths
#define delayus             6  // pulse length for IR modulation. value of 6 for use with tsop4838 IR Receiver chip
unsigned long duration_zero=500;
unsigned long duration_one=200;
unsigned long duration_start=800;
unsigned long pulse_delay=500;
unsigned long bytes_delay=2000;

// counters for buttons (for debounce and shot delay) and muzzlefire
volatile int trigger_counter=button_delay;
volatile int recharge_counter=button_delay;
volatile int muzzlefire_counter = 0;
volatile int shot_delay=12; // in units of 20ms

// I2C variables
unsigned int bytecount=0;
unsigned char I2Cvalue_high=0;
unsigned char I2Cvalue_low=0;
unsigned char I2CID=0;

// tagger state variables
volatile boolean tagger_enabled=true;
volatile boolean lasergunsight_enabled = false;
volatile boolean muzzlefire_enabled = true;
volatile boolean machinegun_enabled = false;

// blink variables
float blink_frequency=1.0;
unsigned int blink_duration=1000;
boolean blink_until_stopped=false;
unsigned long blink_start_timestamp=0;
unsigned long blink_timestamp=0;
boolean blink_enable=false;
boolean blink_state=false;

// Struct, that holds the expander bytes for each color
const struct COLOR_CODE_STRUCT{ // has to be adapted to wiring of the RGB-LED at the expander
  const byte red=0b10000000;
  const byte green=0b01000000;
  const byte blue=0b00100000;
  const byte yellow=0b11000000;
  const byte violett=0b10100000;
  const byte turkis=0b01100000;
  const byte white=0b11100000;
  const byte black=0b00000000;
}COLOR_CODE;

// Serial variables
String serial_string = "";         // a string to hold incoming data
boolean serial_stringComplete = false;  // whether the string is complete
const char serial_trigger[5]="t\n"; // constants to send, when the corresponding event has occured in the Timer1 interrupt routine (sending in loop)
const char serial_recharge[5]="r\n";
volatile char *serial_write_pt=0; // pointer, that can be set to one of the constants above
String receivers=""; // can hold a string with all IDs of the connected receivers (for sending to smartphone)
char bt_version[20]; // array to hold string with version of the serial bluetooth adapter

// Game variables, that are send over IR
byte team_ID = 0b01; // 2 bit
byte player_ID = 0b00001; // 5 bit, Player 0 reserved for enviroment
byte weapon_type = 0b00; // 2 bit
byte shot_damage = 0b1111; // 4 bit, mapping to actual damage value happens in the app
// struct, that hold the important player stats
struct PLAYER_STATS_STRUCT
{
  unsigned int life_points;
  unsigned int shield_points;
  unsigned int ammo_points;
  unsigned int ammo_packs;
  unsigned int extra_lifes;
}player_stats;

// variable with data, that is send over IR (parity bits are first set in setup, then on every change)
volatile unsigned int shot = 0 | (team_ID<<13) | (shot_damage<<9) | (player_ID<<3) | (weapon_type<<1);//0b0011111100001001
volatile boolean shot_active=false; // triggers IR shot sending, which happens in loop function and not in Timer1 ISR
String player_color="white"; // current playercolor is hold, to enable blinking to the correct color

// Parity Check function
// Returns 1 (ODD) or 0 (EVEN) parity
int parity (unsigned char x)
{
    x = x ^ x >> 4;
    x = x ^ x >> 2;
    x = x ^ x >> 1;
    return x & 1;
}

void update_shot_parity_bits(){
  // fill shot parity bits for each shot byte (even parity) --> 0 --> even number of 1s,  1--> odd number of 1s
  shot = (shot | parity((shot&0xFF00)>>8)<<8);
  shot = (shot | parity((shot&0x00FF)));
}


void setup() {
  update_shot_parity_bits();
  
  Wire.begin(10);                // join i2c bus with address #10
  Wire.onReceive(I2CreceiveEvent); // register event
  write_color("white");         // set initial RGB LED color to white
  Serial.begin(9600);           // start serial for communication with smartphone
  check_bt_version();           // request version of the serial bluetooth module through AT commands
  
  // configure button pins
  pinMode(trigger_pin,INPUT_PULLUP);
  pinMode(recharge_pin,INPUT_PULLUP);

  // configure outputs
  pinMode(ir_led, OUTPUT);
  pinMode(rled,OUTPUT);
  pinMode(ammo_indicator_pin,OUTPUT);
  pinMode(laser_gunsight_pin,OUTPUT);
  pinMode(muzzlefire_pin,OUTPUT);

  // load ir config constants from EEPROM
  // duration start
  if(EEPROM.read(0)!= 255 || EEPROM.read(1)!= 255){
    duration_start = (EEPROM.read(0)<<8) | EEPROM.read(1);
  } else {
    duration_start = DEFAULT_DURATION_START;
    EEPROM.update(0, (duration_start&0xFF00)>>8);
    EEPROM.update(1, duration_start&0xFF);
  }
  if(EEPROM.read(2)!= 255 || EEPROM.read(3)!= 255){
    duration_one = (EEPROM.read(2)<<8) | EEPROM.read(3);
  } else {
    duration_one = DEFAULT_DURATION_ONE;
    EEPROM.update(2, (duration_one&0xFF00)>>8);
    EEPROM.update(3, duration_one&0xFF);
  }
  if(EEPROM.read(4)!= 255 || EEPROM.read(5)!= 255){
    duration_zero = (EEPROM.read(4)<<8) | EEPROM.read(5);
  } else {
    duration_zero = DEFAULT_DURATION_ZERO;
    EEPROM.update(4, (duration_zero&0xFF00)>>8);
    EEPROM.update(5, duration_zero&0xFF);
  }
  if(EEPROM.read(6)!= 255 || EEPROM.read(7)!= 255){
    pulse_delay = (EEPROM.read(6)<<8) | EEPROM.read(7);
  } else {
    pulse_delay = DEFAULT_PULSE_DELAY;
    EEPROM.update(6, (pulse_delay&0xFF00)>>8);
    EEPROM.update(7, pulse_delay&0xFF);
  }

  // Init Timer1 with its corresponding ISR to detect button presses and handle muzzlefire
  Timer1.initialize(20000); // 20000us = 20ms between each interrupt
  Timer1.attachInterrupt( button_timer_ISR ); // attach the service routine here
}
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
